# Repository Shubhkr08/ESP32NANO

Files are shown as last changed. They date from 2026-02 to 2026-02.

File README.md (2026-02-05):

# ESP32NANO
I made a custom Esp32 board based on ESP32-S3-WROOM-1 , it has a USB type C and i tried to keep the size of the board as small as possible and to have as much as useful pins available on the board.
<br>Screenshot (42)
<br>
## Overview
This project is a **compact 2-layer development board** based on the **ESP32-S3-WROOM-1 module**. It exposes **all usable GPIOs**, includes onboard **3.3V regulation**, and USB connectivity for easy programming and prototyping. 
The goal of this project is to **learn PCB design, microcontroller integration, and embedded programming**, while creating a versatile dev board for IoT, robotics, and electronics experiments.
## Features
- ESP32-S3-WROOM-1 module (Wi-Fi + Bluetooth 5.0)
- 2-layer compact PCB
- All GPIOs broken out (total 16+17= 33)
- USB connection for programming and power
- Onboard 3.3V voltage regulation
- Compact footprint for small projects
- Educational focus for learning MCU integration and PCB design
- ## Bill of Materials (BOM)
| Qty | Manufacturer Part Number | Description | Supplier | Unit Price (USD) | Total (USD) |
|----:|---|---|---|---|---|
| 1 | ESP32-S3-WROOM-1-N16R8 | RF TXRX MODULE BT PCB TRACE SMD | DigiKey (digikey.in) | 6.56 | 6.56 |
| 1 | USB4125-GF-A | USB Type-C Receptacle 6-Pin SMD | DigiKey (digikey.in) | 0.57 | 0.57 |
| 5 | AMS1117-3.3 | 3.3V Linear Regulator | DigiKey (digikey.in) | 0.27 | 1.35 |
| 2 | PTS810SJG250SMTR LFS | Tactile Switch SPST-NO | DigiKey (digikey.in) | 0.57 | 1.14 |
| 1 | RS0805CT-1000GN-90TRD | 100Ω RF Resistor | DigiKey (digikey.in) | 2.90 | 2.90 |
| 1 | T529P106M010AAE200 | 10µF Tantalum Capacitor | DigiKey (digikey.in) | 1.26 | 1.26 |
| 1 | T529P226M010AAE200 | 22µF Tantalum Capacitor | DigiKey (digikey.in) | 1.32 | 1.32 |
| 1 | CL21B105KBFNNNE | 1µF Ceramic Capacitor | DigiKey (digikey.in) | 0.08 | 0.08 |
| 1 | CL21A226MAYNNNE | 22µF Ceramic Capacitor | DigiKey (digikey.in) | 0.08 | 0.08 |
| 2 | C0805C104K5RACTU | 0.1µF Ceramic Capacitor | DigiKey (digikey.in) | 0.08 | 0.16 |
| 2 | RC0805JR-075K1L | 5.1kΩ Resistor | DigiKey (digikey.in) | 0.10 | 0.20 |
| 1 | RC0805JR-0710KL | 10kΩ Resistor | DigiKey (digikey.in) | 0.10 | 0.10 |

### 🖨️ PCB & Shipping

- **DigiKey Shipping:** $20.00  
- **PCB + Stencil + Shipping:** $28.81 (JLCPCB)  
- **PCB Manufacturer:** JLCPCB — https://jlcpcb.com/

### 💰 Cost Summary

- **Components Total:** $21.72  
- **Shipping + PCB:** $48.81  
- **Estimated Total Cost:** **$70.53 USD**
## Schematic & PCB
Screenshot (39)
Screenshot (60)

- ## 3d Render<br><br>
Screenshot (54)
Screenshot (55)
Screenshot (56)

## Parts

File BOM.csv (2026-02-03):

Index | Quantity | Part Number | Manufacturer Part Number | Description | Customer Reference | Available | Backorder | Unit Price | Extended Price USD
1 | 1 | 5407-ESP32-S3-WROOM-1-N16R8CT-ND | ESP32-S3-WROOM-1-N16R8 | RF TXRX MODULE BT PCB TRACE SMD | DigiKey.in | 1 | 0 | 6.56000 | 6.56
2 | 1 | 2073-USB4125-GF-ACT-ND | USB4125-GF-A | CONN RCPT TYPE C 6P SMD RA | DigiKey.in | 1 | 0 | 0.57000 | 0.57
3 | 5 | 5272-AMS1117-3.3CT-ND | AMS1117-3.3 | IC REG LINEAR 3.3V 1A SOT-223-3L | DigiKey.in | 5 | 0 | 0.27000 | 1.35
4 | 2 | CKN10504CT-ND | PTS810SJG250SMTR LFS | SWITCH TACTILE SPST-NO 0.05A 16V | DigiKey.in | 2 | 0 | 0.57000 | 1.14
5 | 1 | 4353-RS0805CT-1000GN-90TRDCT-ND | RS0805CT-1000GN-90TRD | 250MW 100OHM AL2O3 RF FLIP CHIP | DigiKey.in | 1 | 0 | 2.90000 | 2.90
6 | 1 | 399-17689-1-ND | T529P106M010AAE200 | CAP TANT POLY 10UF 10V 0805 | DigiKey.in | 1 | 0 | 1.26000 | 1.26
7 | 1 | 399-10534-1-ND | T529P226M010AAE200 | CAP TANT POLY 22UF 10V 0805 | DigiKey.in | 1 | 0 | 1.32000 | 1.32
8 | 1 | 1276-1029-1-ND | CL21B105KBFNNNE | CAP CER 1UF 50V X7R 0805 | DigiKey.in | 1 | 0 | 0.08000 | 0.08
9 | 1 | 1276-CL21A226MAYNNNECT-ND | CL21A226MAYNNNE | CAP CER 22UF 25V X5R 0805 | DigiKey.in | 1 | 0 | 0.08000 | 0.08
10 | 2 | 399-C0805C104K5RACTUCT-ND | C0805C104K5RACTU | CAP CER 0.1UF 50V X7R 0805 | DigiKey.in | 2 | 0 | 0.08000 | 0.16
11 | 2 | 311-5.1KARCT-ND | RC0805JR-075K1L | RES 5.1K OHM 5% 1/8W 0805 | DigiKey.in | 2 | 0 | 0.10000 | 0.20
12 | 1 | 311-10KARCT-ND | RC0805JR-0710KL | RES 10K OHM 5% 1/8W 0805 | DigiKey.in | 1 | 0 | 0.10000 | 0.10
13 | 1 | DigiKey Shipping Fee |  | DigiKey Shipping Fee | DigiKey.in | 1 | 0 | 20.0 | 20.0
14 | 1 | JLCPCB PCB,Stencil and Shipping |  | PCB,Stencil and Shipping Fee | https://jlcpcb.com/ | 1 | 0 | 28.81 | 28.81

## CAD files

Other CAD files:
ESP32NANO/CAD/ESP32NANO.f3d

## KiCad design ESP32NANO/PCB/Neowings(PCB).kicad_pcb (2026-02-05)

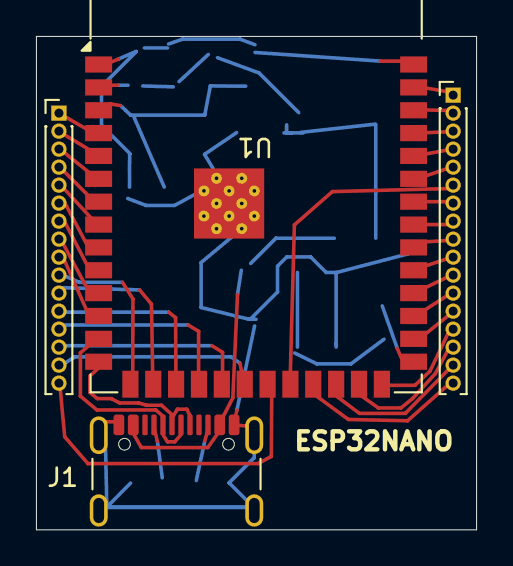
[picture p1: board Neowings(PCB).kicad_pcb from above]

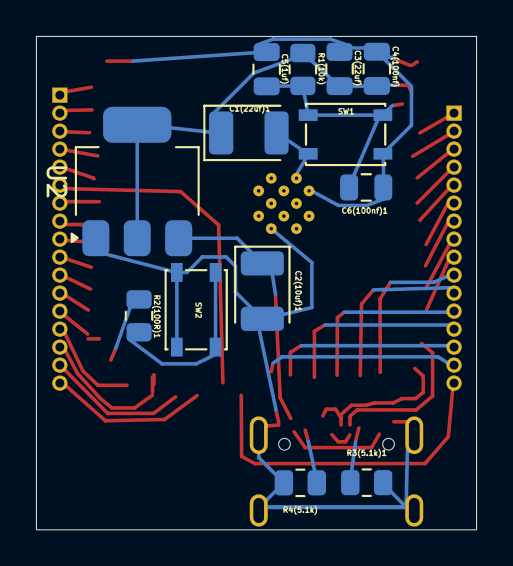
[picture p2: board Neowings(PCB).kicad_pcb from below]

Board: 2 copper layers, 24.5 x 27.4 mm, 17 parts (13 on the bottom side), 43 nets.

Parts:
C1(22uf)1, C2(10uf)1: C_Polarized; CP_EIA-3528-21_Kemet-B
C3(22uf), C4(100nf), C5(1uf), C6(100nf)1: C; C_0805_2012Metric
IO1: Conn_01x16_Pin; PinHeader_1x16_P1.00mm_Vertical
J1: USB_C_Receptacle_USB2.0_16P; USB_C_Receptacle_GCT_USB4105-xx-A_16P_TopMnt_Horizontal
J3: Conn_01x17_Pin; PinHeader_1x17_P1.00mm_Vertical
R1(10k), R2(100R)1, R3(5.1k)1, R4(5.1k): R; R_0805_2012Metric
SW1, SW2: SW_Push; SW_SPST_PTS810
U1: ESP32-S3-WROOM-1
U2: AMS1117-3.3; SOT-223-3_TabPin2

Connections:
+3.3V: C1(22uf)1.1, C3(22uf).1, C4(100nf).1, R1(10k).1, U1.2 (3V3), U2.2 (VO)
+5V: C2(10uf)1.1, J1.A4 (VBUS), J1.A9 (VBUS), J1.B4 (VBUS), J1.B9 (VBUS), U2.3 (VI)
BOOT: R2(100R)1.1, U1.27 (IO0)
D+: J1.A6 (D+), J1.B6 (D+), U1.14 (USB_D+)
D-: J1.A7 (D-), J1.B7 (D-), U1.13 (USB_D-)
EN: C5(1uf).1, C6(100nf)1.1, R1(10k).2, SW1.1, U1.3 (EN)
GND: C1(22uf)1.2, C2(10uf)1.2, C3(22uf).2, C4(100nf).2, C5(1uf).2, C6(100nf)1.2, J1.A1 (GND), J1.A12 (GND), J1.B1 (GND), J1.B12 (GND), J1.S1 (SHIELD), R3(5.1k)1.2, R4(5.1k).2, SW1.2, SW2.2, U1.1 (GND), U1.40 (GND), U1.41 (GND), U2.1 (GND)
unnamed: IO1.1, U1.4 (IO4)
unnamed: IO1.2, U1.5 (IO5)
unnamed: IO1.3, U1.6 (IO6)
unnamed: IO1.4, U1.7 (IO7)
unnamed: IO1.5, U1.8 (IO15)
unnamed: IO1.6, U1.9 (IO16)
unnamed: IO1.7, U1.10 (IO17)
unnamed: IO1.8, U1.11 (IO18)
unnamed: IO1.9, U1.12 (IO8)
unnamed: IO1.10, U1.15 (IO3)
unnamed: IO1.11, U1.16 (IO46)
unnamed: IO1.12, U1.17 (IO9)
unnamed: IO1.13, U1.18 (IO10)
unnamed: IO1.14, U1.19 (IO11)
unnamed: IO1.15, U1.20 (IO12)
unnamed: IO1.16, U1.21 (IO13)
unnamed: J1.A5 (CC1), R3(5.1k)1.1
unnamed: J1.B5 (CC2), R4(5.1k).1
unnamed: J3.1, U1.39 (IO1)
unnamed: J3.2, U1.38 (IO2)
unnamed: J3.3, U1.37 (TXD0)
unnamed: J3.4, U1.36 (RXD0)
unnamed: J3.5, U1.35 (IO42)
unnamed: J3.6, U1.22 (IO14)
unnamed: J3.7, U1.34 (IO41)
unnamed: J3.8, U1.33 (IO40)
unnamed: J3.9, U1.32 (IO39)
unnamed: J3.10, U1.31 (IO38)
unnamed: J3.11, U1.30 (IO37)
unnamed: J3.12, U1.29 (IO36)
unnamed: J3.13, U1.28 (IO35)
unnamed: J3.14, U1.26 (IO45)
unnamed: J3.15, U1.25 (IO48)
unnamed: J3.16, U1.24 (IO47)
unnamed: J3.17, U1.23 (IO21)
unnamed: R2(100R)1.2, SW2.1
